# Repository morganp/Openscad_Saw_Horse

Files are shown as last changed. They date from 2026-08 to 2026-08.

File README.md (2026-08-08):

# Folding Saw Horse Bracket

Parametric OpenSCAD bracket that turns **straight cut 86 x 37 mm timber** into a
folding A-frame trestle saw horse. Two brackets per horse. Every timber part is
a plain square cross-cut: no miters, no sawn notches, all joinery angles live in
the printed part.

Version **0.2.0**. Model: [`saw_horse_bracket.scad`](saw_horse_bracket.scad).
Remaining work: [`todo.md`](todo.md).

**[Open in SCAD Studio](https://lizard-spock.co.uk/openscad-gui/?github=morganp/Openscad_Saw_Horse/saw_horse_bracket.scad)**
- renders in the browser, no install needed.

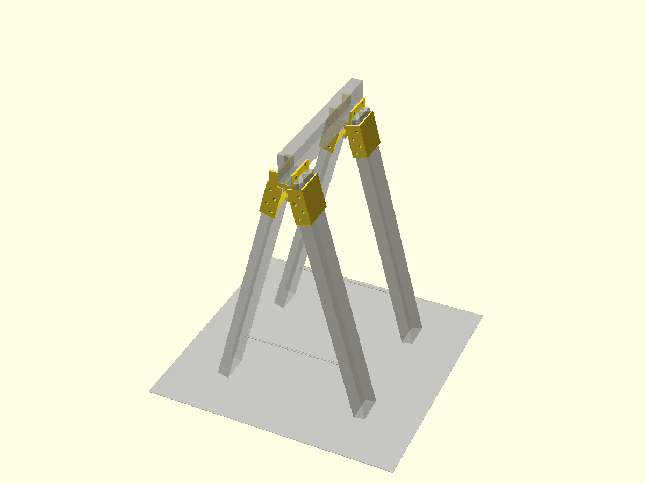
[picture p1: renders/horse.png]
Assembled saw horse


## How it works

Each bracket is two printed parts on a single M8 bolt hinge:

- **Fixed body**: rail notch head, an open three-sided channel holding one leg
  at -15 degrees, and a two-lug clevis for the hinge bolt.
- **Swing leaf**: central hinge lug, an arm to an inner bar, and a mirrored
  open channel for the second leg at +15 degrees.

| Fixed body | Swing leaf |
|---|---|
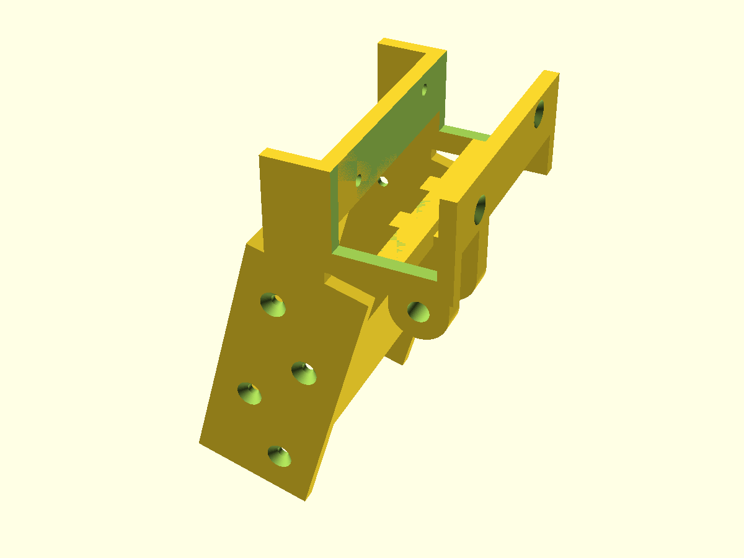
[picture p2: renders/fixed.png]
Fixed body
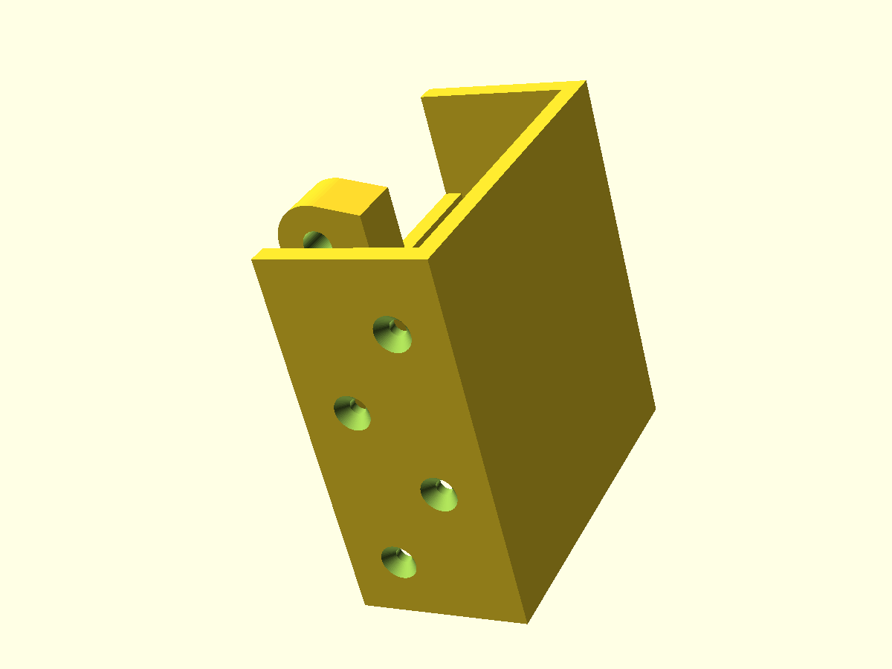
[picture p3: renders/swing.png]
Swing leaf
|  |  |

### Timber-to-timber load path

Each leg's square-cut top face bears **directly** against the rail's bottom
edges. The leg top is inset `bear_inset` under the rail so the rail's bottom
corner lands on flat end grain. Vertical load runs rail to leg end grain to
floor. All plastic under the rail is relieved 1.5 mm, so the rail physically
cannot sit on plastic.

The printed parts only locate the timber, hold the splay angle, carry the fold
hinge and take screws.

### Open channels

Legs sit in three-sided channels: two side walls (screwed to the leg's wide
faces) plus an outer wall. The inner face, toward the centre of the horse, is
open. This dropped solid volume from 816 cm3 to 307 cm3 per bracket, **62 percent
less filament** than the closed-sleeve version.

### The cord is required

There is no printed stop. The open position is held by a **cord, rope or webbing
tie between the two legs of each A-frame** near the floor. The horse is a truss:
legs in compression, cord in tension.

> **Without the cord fitted the legs can over-splay and the hinge lugs become
> the fuse. Do not load the horse until the ties are on.**

A screwed-on timber batten works instead if the horse can stay assembled, but it
blocks folding.

| One A-frame open (cord shown) | Folded flat |
|---|---|
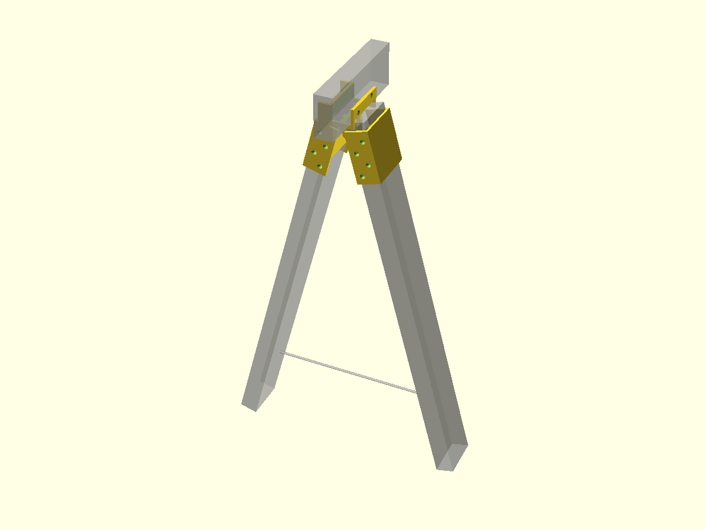
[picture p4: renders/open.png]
Open
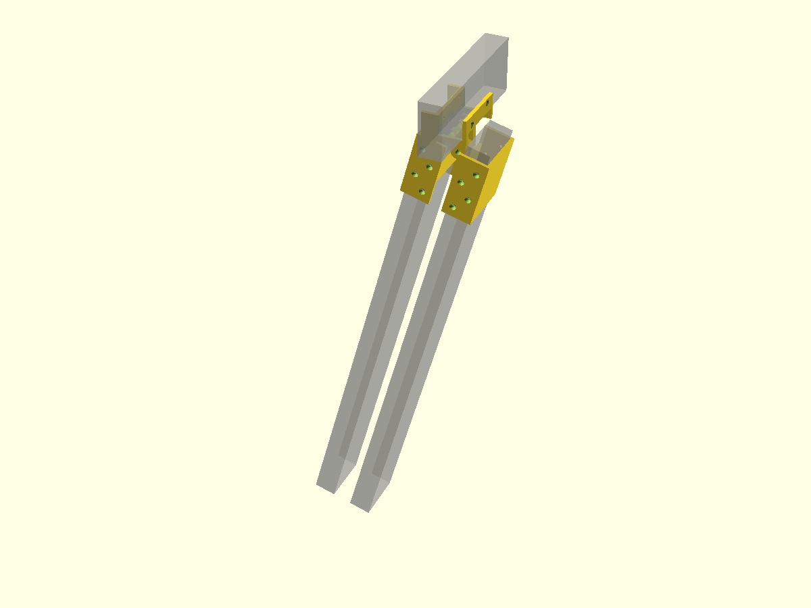
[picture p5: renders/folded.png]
Folded
|  |  |

## Cut list

Working height 850 mm, splay 15 degrees, notch outer span 480 mm.

| Part | Qty | L x W x T (mm) | Cut |
|---|-----|---|-----|
| Rail | 1 | 480 x 86 x 37 | square both ends, flush with notch heads |
| Leg  | 4 | 788 x 86 x 37 | square both ends |
| Cord | 2 | ~341 span + knots | tie between leg pair, 150 mm above floor |

Leg length = `(765.7 - 18.5 * sin 15) / cos 15` = 787.7, cut 788 and trim to
sit. Cord span between leg inner faces at height `h`:

```
span(h) = 2 * (24.8 + (765.7 - h) * tan 15 - 19.15)
```

= 341 mm at the default `cord_tie_h` = 150. Footprint in the fold plane 498 mm.
Height fine-tuning: trim the legs, 1 mm of leg is about 0.97 mm of height.

Timber: 2 x 2.4 m lengths of 86 x 37 cover 4 legs plus the rail with 3 mm kerf
allowance.

## Hardware (per horse, 2 brackets)

- 2x M8 x 50 hex bolt + nyloc nut, 4x 25 mm OD penny washers
- 20x 4.5 x 40 countersunk wood screws (16 legs, 4 rail)
- ~2 m of 4-6 mm cord

## Printing

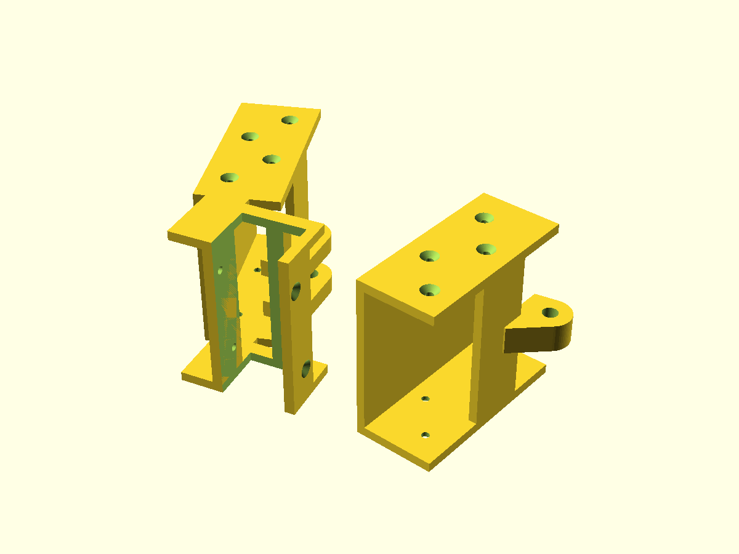
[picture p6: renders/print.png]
Print orientation


Print each part **lying on a side face** (the `print` show mode lays them down).
Layer planes are then parallel to the fold plane, so channel walls, plates and
lugs load in-plane and the hinge bore prints as a vertical hole. Mostly plate
geometry, little to no support needed.

Tough PLA, 4-5 perimeters, 25-40 percent infill.

## Usage

In the browser, no install:
[SCAD Studio](https://lizard-spock.co.uk/openscad-gui/?github=morganp/Openscad_Saw_Horse/saw_horse_bracket.scad).

Locally, requires [BOSL2](https://github.com/BelfrySCAD/BOSL2):

```bash
openscad saw_horse_bracket.scad
```

Set `show_mode` near the top of the file:

| Mode | Shows |
|---|---|
| `"open"` | one bracket with ghost timber, default |
| `"fixed"` | fixed body alone |
| `"swing"` | swing leaf alone |
| `"folded"` | fold-flat position |
| `"horse"` | full trestle |
| `"print"` | both parts laid flat for slicing |

Key parameters: `working_height` (850), `notch_outside_span` (480), `timber_w` /
`timber_t` (86 / 37), `timber_clr` (0.5 per face), `splay` (15), `bolt_d` (8),
`cord_tie_h` (150). Measure your actual sawn stock and set `timber_w` /
`timber_t` to real values before printing.

## Status

Not yet test printed. Clearances (0.5 mm timber, 0.4 mm bolt) are unverified.
See [`todo.md`](todo.md) for the test and tuning checklist.

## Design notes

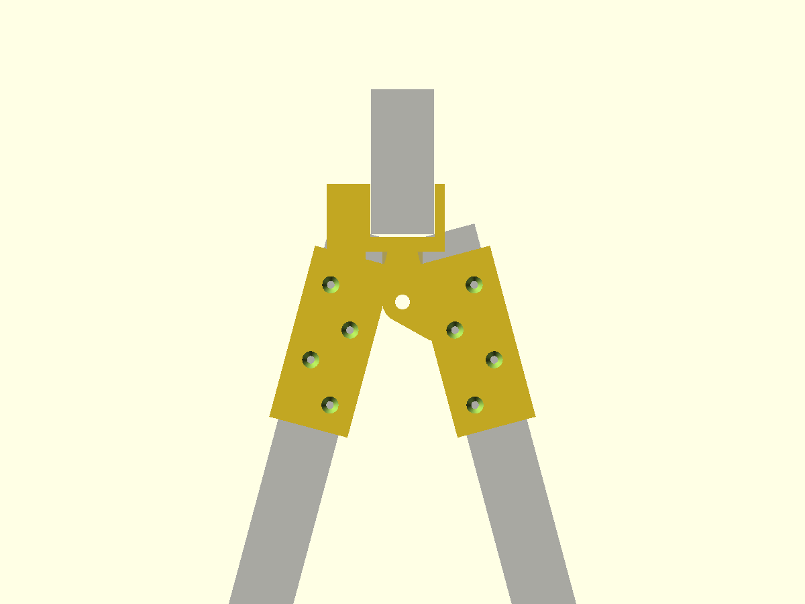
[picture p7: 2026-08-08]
renders/open_side.png

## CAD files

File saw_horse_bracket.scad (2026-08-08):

// Folding saw horse hinge bracket, v0.2.0
//
// A pair of these brackets turns straight cut 86x37 timber into a folding
// A-frame trestle saw horse. Each bracket is two printed parts joined by a
// single M8 bolt hinge:
//   fixed body  : rail notch head, open three-sided channel for one leg at
//                 -splay, and a two-lug clevis for the hinge bolt
//   swing leaf  : central hinge lug, arm to an inner bar on the leg, and a
//                 mirrored open channel for the second leg at +splay
//
// v0.2.0 design rules:
//   TIMBER-TO-TIMBER LOAD PATH. Each leg's square-cut top face bears
//   directly against the rail's bottom edges: the leg top is inset
//   bear_inset under the rail, so the rail's bottom corner lands on the
//   flat end grain and the leg tip rises beside the rail's side face.
//   Vertical load runs rail -> leg end grain -> floor. The printed parts
//   only locate the parts, hold the splay angle, carry the fold hinge and
//   take screws. All plastic under the rail is relieved 1.5 mm so the rail
//   can never sit on plastic.
//   OPEN CHANNELS. Each leg sits in a three-sided channel: two side walls
//   (screwed to the leg's wide faces) and an outer wall. The inner face,
//   toward the centre of the horse, is open to save filament.
//   NO PRINTED STOP. The open position is held by a cord, rope or webbing
//   tie between the two legs of each A-frame near the floor (the horse is
//   a truss: legs in compression, cord in tension). The cord is REQUIRED
//   in use; without it the legs can over-splay. Cord length is echoed and
//   in the cut list. A screwed-on timber batten is an alternative if the
//   horse can stay assembled.
//   Every timber part is a plain square cross-cut, no miters, no notches.
//   Legs sit in the conventional orientation: wide 86 face along the horse,
//   37 edge in the fold plane. Notch outer span 480, rail on edge, ends
//   flush with the notch heads.
//
// Library: BOSL2 (anchored primitives, diff/tag booleans).
//
// Print notes (Tough PLA):
//   Print each part lying on a side face (the "print" show_mode lays them
//   down). Layer planes are then parallel to the fold plane: channel walls,
//   plates and lugs are loaded in-plane, and the hinge bore prints as a
//   vertical hole. Mostly plate geometry, little to no support needed.
//   4-5 perimeters, 25-40 percent infill.
//
// Hardware per bracket:
//   1x M8 x 50 bolt + nyloc nut + 2 penny washers (25 mm OD). The steel
//     bolt is the pivot bearing; the hinge carries only fold and carry
//     loads, not the working load.
//   8x 4.5 x 40 countersunk wood screws (4 per leg through the side walls).
//   2x 4.5 x 40 countersunk wood screws for the rail (through the cheeks).
// Per horse additionally: ~2 m of 4-6 mm cord (one tie per A-frame).
//
// show_mode: "open" (default, one bracket + ghost timber), "fixed", "swing",
//            "folded", "horse" (full trestle), "print" (parts laid flat)

include <BOSL2/std.scad>
$fn = 64;

show_mode = "open";

// ---------- timber and overall geometry (mm, deg) ----------
working_height     = 850;  // floor to top of rail
notch_outside_span = 480;  // outer faces of the two notch heads, rail length
rail_length        = notch_outside_span; // rail ends flush with head faces
timber_w           = 86;   // timber wide face
timber_t           = 37;   // timber thin face
timber_clr         = 0.5;  // channel clearance per face, sawn stock varies
splay              = 15;   // leg angle from vertical, each side, fold plane

// ---------- printed part parameters ----------
wall_side      = 5.5;   // channel side walls, take the leg screws
wall_outer     = 5;     // channel outer wall
cheek_wall     = 6;     // rail notch cheek walls
bolt_d         = 8;     // hinge pivot bolt, M8
bolt_hole_clr  = 0.4;   // radial clearance per side of bolt hole
screw_d        = 4.5;   // wood screw shank clearance
screw_cs_d     = 10.5;  // countersink mouth diameter
lug_r          = 12;    // hinge lug radius
lug_t_fixed    = 10;    // each fixed clevis lug thickness
lug_t_swing    = 16;    // central swing lug thickness
lug_gap        = 0.5;   // side clearance per lug face
hinge_drop     = 40;    // rail underside height above the pivot axis
bear_inset     = 12;    // rail bottom corner inset from leg's inner top edge
rail_relief    = 1.5;   // plastic relieved below rail so timber bears first
ch_len         = 105;   // leg channel length along the leg
ch_top_gap     = 15;    // channel starts this far below the leg top face
cord_tie_h     = 150;   // cord tie height above the floor

// ---------- derived ----------
cav_x       = timber_t + 2*timber_clr;   // 38, channel width in fold plane
cav_y       = timber_w + 2*timber_clr;   // 87, channel width along the bolt
head_w      = cav_y + 2*wall_side;       // 98, notch head width along horse
slot_w      = timber_t + 2*timber_clr;   // 38, rail slot width, rail on edge
a_bear      = timber_t/2 - bear_inset;   // bearing point offset from leg axis
leg_top_x   = timber_t/2 + a_bear*cos(splay);  // leg top face centre, from pivot
leg_top_z   = hinge_drop + a_bear*sin(splay);
leg_tip_z   = hinge_drop + (a_bear + timber_t/2)*sin(splay); // tip beside rail
cheek_z0    = leg_tip_z + 1;             // cheeks start above the leg tips
cheek_z1    = hinge_drop + 30;           // rail captured 30 above its base
floor_web_z = hinge_drop - rail_relief;  // top of all plastic under the rail
rail_top_z  = hinge_drop + timber_w;
floor_z     = rail_top_z - working_height;
bracket_y   = notch_outside_span/2 - head_w/2;  // bracket station centres
lug_pitch   = lug_t_swing/2 + lug_gap + lug_t_fixed/2; // fixed lug centres
// Legs are square cut; the heel corner touches the floor, the top face
// centre sits at leg_top_z. The 37 edge is in the tilt plane.
leg_len_exact = (leg_top_z - floor_z - (timber_t/2)*sin(splay))/cos(splay);
leg_len       = round(leg_len_exact);
foot_span     = 2*(leg_top_x + (leg_top_z - floor_z)*tan(splay)
                   + (timber_t/2)/cos(splay));
// Cord between the legs' inner faces at the tie height (per A-frame).
z_tie      = floor_z + cord_tie_h;
cord_len   = 2*(leg_top_x + (leg_top_z - z_tie)*tan(splay)
                - (timber_t/2)/cos(splay));

echo(str("CUT LIST per horse: 1 rail ", rail_length, " x ", timber_w, " x ",
         timber_t, ", 4 legs ", leg_len, " x ", timber_w, " x ", timber_t,
         ", all square cuts"));
echo(str("leg length exact = ", leg_len_exact, " mm"));
echo(str("footprint in fold plane = ", foot_span, " mm"));
echo(str("cord tie, inner face to inner face at ", cord_tie_h,
         " above floor = ", cord_len, " mm per A-frame"));

// ---------- helpers ----------

// Through hole along X with countersinks both ends. One screw per hole,
// drive from either side.
module cs_xhole(l) {
    xcyl(d=screw_d, l=l+2);
    translate([ l/2 - 1.4, 0, 0]) xcyl(d1=screw_d, d2=screw_cs_d, l=3.2);
    translate([-l/2 + 1.4, 0, 0]) xcyl(d1=screw_cs_d, d2=screw_d, l=3.2);
}

// Same along Y, for the leg screws through the channel side walls.
module cs_yhole(l) {
    ycyl(d=screw_d, l=l+2);
    translate([0,  l/2 - 1.4, 0]) ycyl(d1=screw_d, d2=screw_cs_d, l=3.2);
    translate([0, -l/2 + 1.4, 0]) ycyl(d1=screw_cs_d, d2=screw_d, l=3.2);
}

// Open three-sided leg channel, local frame: leg axis -Z, leg top face
// centre at origin. Outer wall on local -X, inner face (+X) open except for
// one low strap that boxes the channel and joins the walls into one printed
// body. The channel starts ch_top_gap below the top face so nothing printed
// reaches the rail contact zone.
module leg_channel() {
    for (sy = [-1, 1])
        translate([0, sy*(cav_y + wall_side)/2, -ch_top_gap])
            cuboid([cav_x + 2*wall_outer, wall_side, ch_len], anchor=TOP);
    translate([-(cav_x + wall_outer)/2, 0, -ch_top_gap])
        cuboid([wall_outer, cav_y + 2*wall_side, ch_len], anchor=TOP);
    // inner strap, low on the channel to stay clear of the hinge lugs
    translate([(cav_x + wall_outer)/2, 0, -ch_top_gap - 30])
        cuboid([wall_outer, cav_y + 2*wall_side, 35], anchor=TOP);
}

module leg_channel_screws() {
    for (i = [0:3])
        translate([(i%2 == 0 ? -9 : 9), 0, -35 - i*23])
            cs_yhole(cav_y + 2*wall_side);
}
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

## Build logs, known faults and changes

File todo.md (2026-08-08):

# Openscad Saw Horse - todo

Model: `saw_horse_bracket.scad` (v0.2.0, BOSL2). Renders in `renders/`.
v0.2.0: timber-to-timber load path, open leg channels, single-bolt hinge,
cord holds the splay (no printed stop). Solid volume per bracket 307 cm3
vs 816 cm3 in v0.1 (62 percent less).

## Print and fit testing
- [ ] Test print one fixed body + one swing leaf in Tough PLA, lying on the
      side face as in the `print` show_mode (layers parallel to the fold
      plane). 4-5 perimeters, 25-40 percent infill.
- [ ] Check timber fit in the open channels and rail slot with real sawn
      stock; tune `timber_clr` (0.5 per face). Measure the batch first and
      set `timber_w` / `timber_t` to actuals.
- [ ] Check M8 x 50 bolt through the clevis (`bolt_hole_clr` 0.4); leaf must
      swing freely with the nyloc snugged.
- [ ] Assemble one A-frame: legs screwed in channels, rail dropped in,
      confirm both rail bottom corners land on the leg end grain and the
      plastic blade below stays 1.5 mm clear (`rail_relief`).
- [ ] Fit the cord tie and load test gradually: legs are in compression,
      cord in tension. THE CORD IS REQUIRED, without it the legs over-splay.
- [ ] Fold test: legs must swing to parallel, tips clearing the rail.

## Design follow-ups
- [ ] Decide cord anchoring: 8 mm hole drilled through each leg at the tie
      height (simple, but a drilling op), or tied clove hitches around the
      legs, or a screwed-on batten (blocks folding unless removed).
- [ ] Bearing check after load test: the rail's bottom corners bite into
      the leg end grain; some bedding-in is expected and fine. If crushing
      is excessive, increase `bear_inset` to move the contact further onto
      the face.
- [ ] Legs bend about their weak axis in the fold plane (conventional
      commercial-bracket orientation); watch the legs in the load test.
- [ ] Notch spans: outer faces of the two heads 480 apart (`
      notch_outside_span`), head is 98 wide, inner faces 284 apart.
- [ ] Export STLs and tag v0.2.0 once the test print passes (semver).

## Hardware list (per horse = 2 brackets)
- [ ] 2x M8 x 50 hex bolt + nyloc nut, 4x 25 mm OD penny washers
- [ ] 20x 4.5 x 40 countersunk wood screws (16 legs + 4 rail)
- [ ] ~2 m of 4-6 mm cord (one tie per A-frame, ~1 m each with knots)
- [ ] Timber: 2x 2.4 m of 86 x 37 covers 4 legs (788) + rail (480) with
      3 mm kerf allowance (3 legs from one length, leg + rail from the other)

## Cut list (working height 850, splay 15 deg)
| Part | Qty | L x W x T (mm) | Cut |
|---|-----|---|-----|
| Rail | 1 | 480 x 86 x 37 | square both ends, flush with notch heads |
| Leg  | 4 | 788 x 86 x 37 | square both ends |
| Cord | 2 | ~341 span + knots | tie between leg pair at 150 above floor |

Leg length = (top-face-centre drop 765.7 - heel corner rise 18.5*sin 15) /
cos 15 = 787.7, cut 788 and trim to sit. Cord span between leg inner faces
at height h above the floor:
  span(h) = 2 * (24.8 + (765.7 - h) * tan 15 - 19.15)
= 341 mm at the default h = 150 (`cord_tie_h`, echoed by the model).
Footprint in the fold plane 498. Height fine-tuning: trim legs,
1 mm leg = ~0.97 mm height.
